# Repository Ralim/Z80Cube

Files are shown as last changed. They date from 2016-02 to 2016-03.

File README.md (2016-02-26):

# Z80Cube - Project Zeta
A 5 layer 5cm * 5cm cubish shaped z80 machine
Basically designed as a learning experience.
Big difference from other builds I have seen is the entire system runs on a 64K memory space of ram, and the atmega2560 pre-load's the bootloader into the chip on system startup.
This bootloader for the z80 then allows the user to test memory and load + execute programs.

## Layers
* Bus Display ->Led indicators for the bus
* Z80 CPU
* 64K SRAM/ROM
* Power and Programmer (Atmega 2560+flash storage to store the software)

##ToDo:
Basically everything
* Build PCBs
* Test PCBs
* Write the code for the bootloader (Going to use Arduino to keep it easy for others)
* Write arduino code for storing program packages
* Write arduino code for monitoring the bus
* write arduino code for single stepping operation

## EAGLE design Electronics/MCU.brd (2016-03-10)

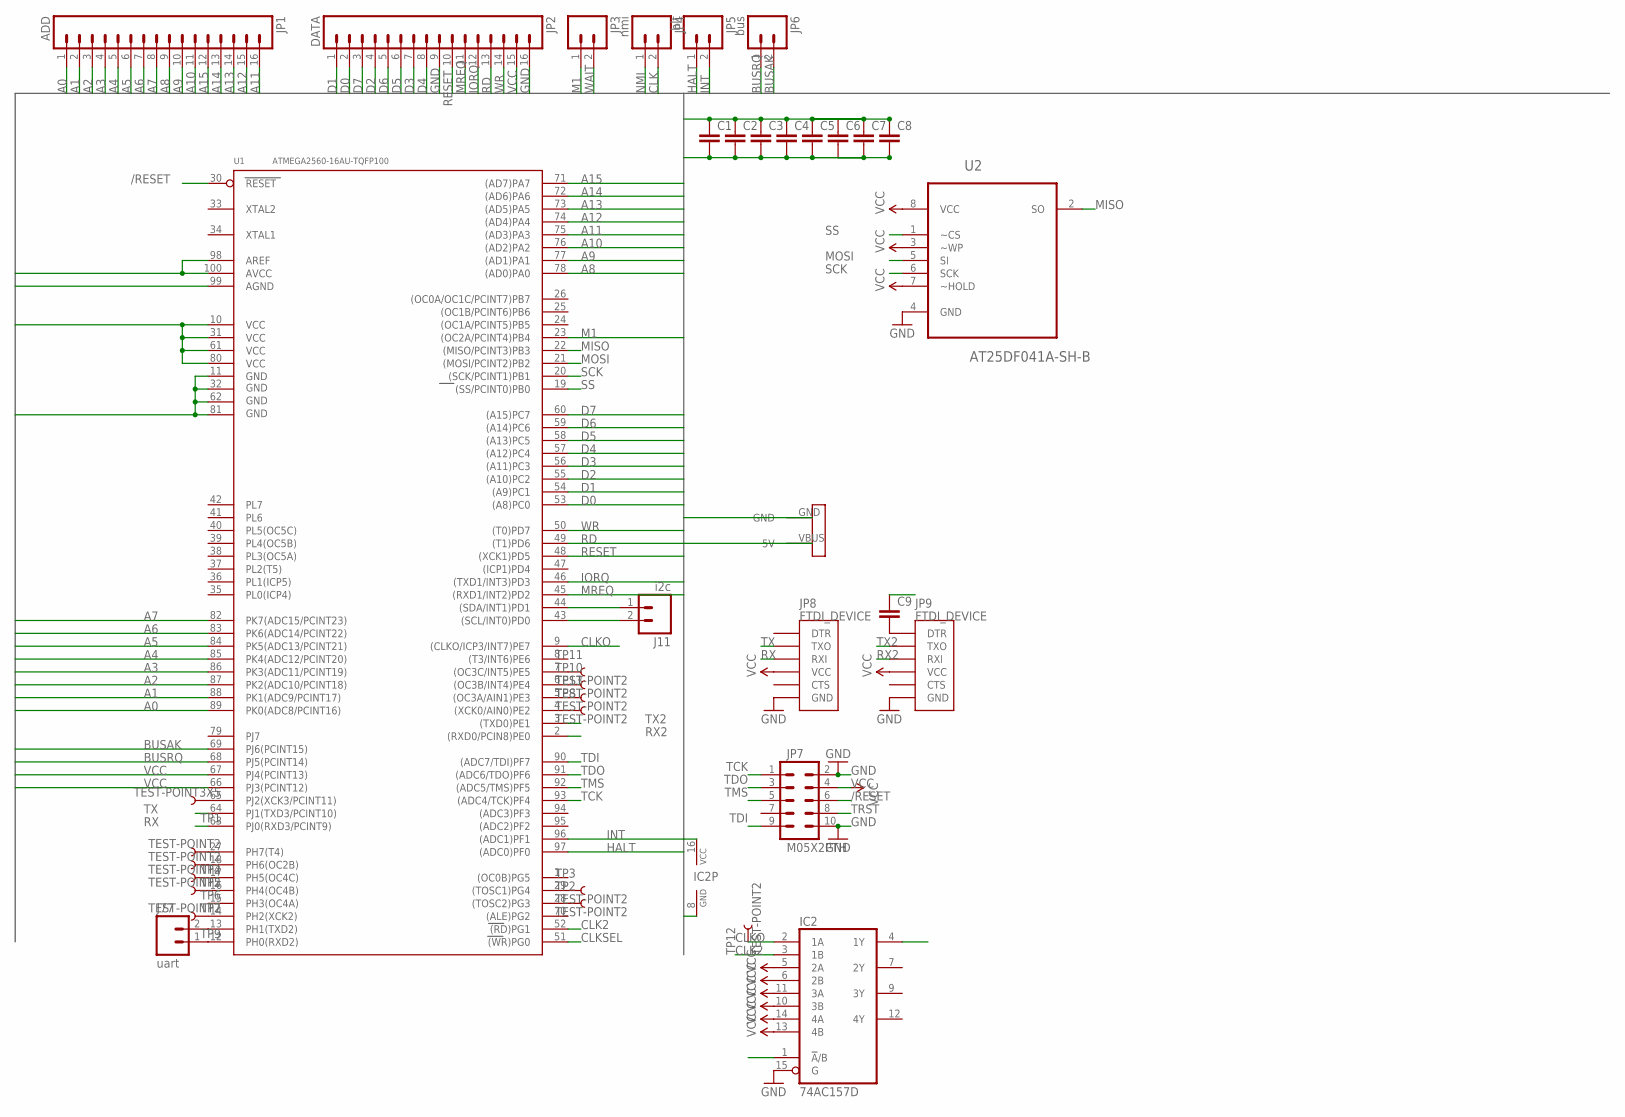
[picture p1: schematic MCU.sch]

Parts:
C1, C2, C3, C4, C5, C6, C7, C8, C9: C-EUC0805; C0805
IC2: 74AC157D; SO16
J11: i2c; 1X02
J77: uart; 1X02
JP1: ADD; 1X16
JP2: DATA; 1X16
JP3: M02PTH; 1X02
JP4: nmi; 1X02
JP5: hlt; 1X02
JP6: bus; 1X02
JP7: M05X2PTH; AVR_ICSP
JP8, JP9: FTDI_DEVICE; FTDI_DEVICE_SIDE
TP1: TEST-POINT3X5; PAD.03X.05
TP2, TP3, TP4, TP5, TP6, TP7, TP8, TP9, TP10, TP11, TP12, TP13: TEST-POINT2; PAD.02X.02
U1: ATMEGA2560-16AU-TQFP100; TQFP100-0.5-14X14MM
U2: AT25DF041A-SH-B; SOIC127P798X216-8N
U$1: USB-MICRO-PWR; USB-MICROB-PWR

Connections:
/RESET: C9.1, JP7.6, U1.30 (RESET)
A0: JP1.1, U1.89 (PK0(ADC8/PCINT16))
A1: JP1.2, U1.88 (PK1(ADC9/PCINT17))
A2: JP1.3, U1.87 (PK2(ADC10/PCINT18))
A3: JP1.4, U1.86 (PK3(ADC11/PCINT19))
A4: JP1.5, U1.85 (PK4(ADC12/PCINT20))
A5: JP1.6, U1.84 (PK5(ADC13/PCINT21))
A6: JP1.7, U1.83 (PK6(ADC14/PCINT22))
A7: JP1.8, U1.82 (PK7(ADC15/PCINT23))
A8: JP1.9, U1.78 ((AD0)PA0)
A9: JP1.10, U1.77 ((AD1)PA1)
A10: JP1.11, U1.76 ((AD2)PA2)
A11: JP1.16, U1.75 ((AD3)PA3)
A12: JP1.15, U1.74 ((AD4)PA4)
A13: JP1.14, U1.73 ((AD5)PA5)
A14: JP1.13, U1.72 ((AD6)PA6)
A15: JP1.12, U1.71 ((AD7)PA7)
BUSAK: JP6.2, U1.69 (PJ6(PCINT15))
BUSRQ: JP6.1, U1.68 (PJ5(PCINT14))
CLK: IC2.4 (1Y), JP4.2
CLK2: IC2.3 (1B), U1.52 ((RD)PG1)
CLKO: IC2.2 (1A), TP12.P$1, U1.9 ((CLKO/ICP3/INT7)PE7)
CLKSEL: IC2.1 (!A!/B), U1.51 ((WR)PG0)
D0: JP2.2, U1.53 ((A8)PC0)
D1: JP2.1, U1.54 ((A9)PC1)
D2: JP2.4, U1.55 ((A10)PC2)
D3: JP2.7, U1.56 ((A11)PC3)
D4: JP2.8, U1.57 ((A12)PC4)
D5: JP2.6, U1.58 ((A13)PC5)
D6: JP2.5, U1.59 ((A14)PC6)
D7: JP2.3, U1.60 ((A15)PC7)
GND: C1.2, C2.2, C3.2, C4.2, C5.2, C6.2, C7.2, C8.2, IC2.8 (GND), IC2.15 (G), JP2.9, JP2.16, JP7.2, JP7.10, JP8.P$6 (GND), JP9.P$6 (GND), U1.11 (GND), U1.32 (GND1), U1.62 (GND2), U1.81 (GND3), U1.99 (AGND), U2.4 (GND), U$1.GND
HALT: JP5.1, U1.97 ((ADC0)PF0)
INT: JP5.2, U1.96 ((ADC1)PF1)
IORQ: JP2.12, U1.46 ((TXD1/INT3)PD3)
M1: JP3.1, U1.23 ((OC2A/PCINT4)PB4)
MISO: U1.22 ((MISO/PCINT3)PB3), U2.2 (SO)
MOSI: U1.21 ((MOSI/PCINT2)PB2), U2.5 (SI)
MREQ: JP2.11, U1.45 ((RXD1/INT2)PD2)
unnamed: J77.1, U1.12 (PH0(RXD2))
unnamed: J77.2, U1.13 (PH1(TXD2))
unnamed: J11.1, U1.44 ((SDA/INT1)PD1)
unnamed: J11.2, U1.43 ((SCL/INT0)PD0)
unnamed: TP1.P$1, U1.65 (PJ2(XCK3/PCINT11))
unnamed: TP2.P$1, U1.28 ((TOSC2)PG3)
unnamed: TP3.P$1, U1.29 ((TOSC1)PG4)
unnamed: TP4.P$1, U1.27 (PH7(T4))
unnamed: TP5.P$1, U1.18 (PH6(OC2B))
unnamed: TP6.P$1, U1.17 (PH5(OC4C))
unnamed: TP7.P$1, U1.16 (PH4(OC4B))
unnamed: TP8.P$1, U1.4 ((XCK0/AIN0)PE2)
unnamed: TP9.P$1, U1.14 (PH2(XCK2))
unnamed: TP10.P$1, U1.6 ((OC3B/INT4)PE4)
unnamed: TP11.P$1, U1.7 ((OC3C/INT5)PE5)
unnamed: C9.2, JP9.P$1 (DTR)
unnamed: TP13.P$1, U1.5 ((OC3A/AIN1)PE3)
NMI: JP4.1
RD: JP2.13, U1.49 ((T1)PD6)
RESET: JP2.10, U1.48 ((XCK1)PD5)
RX: JP8.P$3 (RXI), U1.63 (PJ0(RXD3/PCINT9))
RX2: JP9.P$3 (RXI), U1.2 ((RXD0/PCIN8)PE0)
SCK: U1.20 ((SCK/PCINT1)PB1), U2.6 (SCK)
SS: U1.19 ((SS/PCINT0)PB0), U2.1 (~CS)
TCK: JP7.1, U1.93 ((ADC4/TCK)PF4)
TDI: JP7.9, U1.90 ((ADC7/TDI)PF7)
TDO: JP7.3, U1.91 ((ADC6/TDO)PF6)
TMS: JP7.5, U1.92 ((ADC5/TMS)PF5)
TRST: JP7.8
TX: JP8.P$2 (TXO), U1.64 (PJ1(TXD3/PCINT10))
TX2: JP9.P$2 (TXO), U1.3 ((TXD0)PE1)
VCC: C1.1, C2.1, C3.1, C4.1, C5.1, C6.1, C7.1, C8.1, IC2.5 (2A), IC2.6 (2B), IC2.10 (3B), IC2.11 (3A), IC2.13 (4B), IC2.14 (4A), IC2.16 (VCC), JP2.15, JP7.4, JP8.P$4 (VCC), JP9.P$4 (VCC), U1.10 (VCC), U1.31 (VCC1), U1.61 (VCC2), U1.66 (PJ3(PCINT12)), U1.67 (PJ4(PCINT13)), U1.80 (VCC3), U1.98 (AREF), U1.100 (AVCC), U2.3 (~WP), U2.7 (~HOLD), U2.8 (VCC), U$1.VBUS (5V)
WAIT: JP3.2
WR: JP2.14, U1.50 ((T0)PD7)

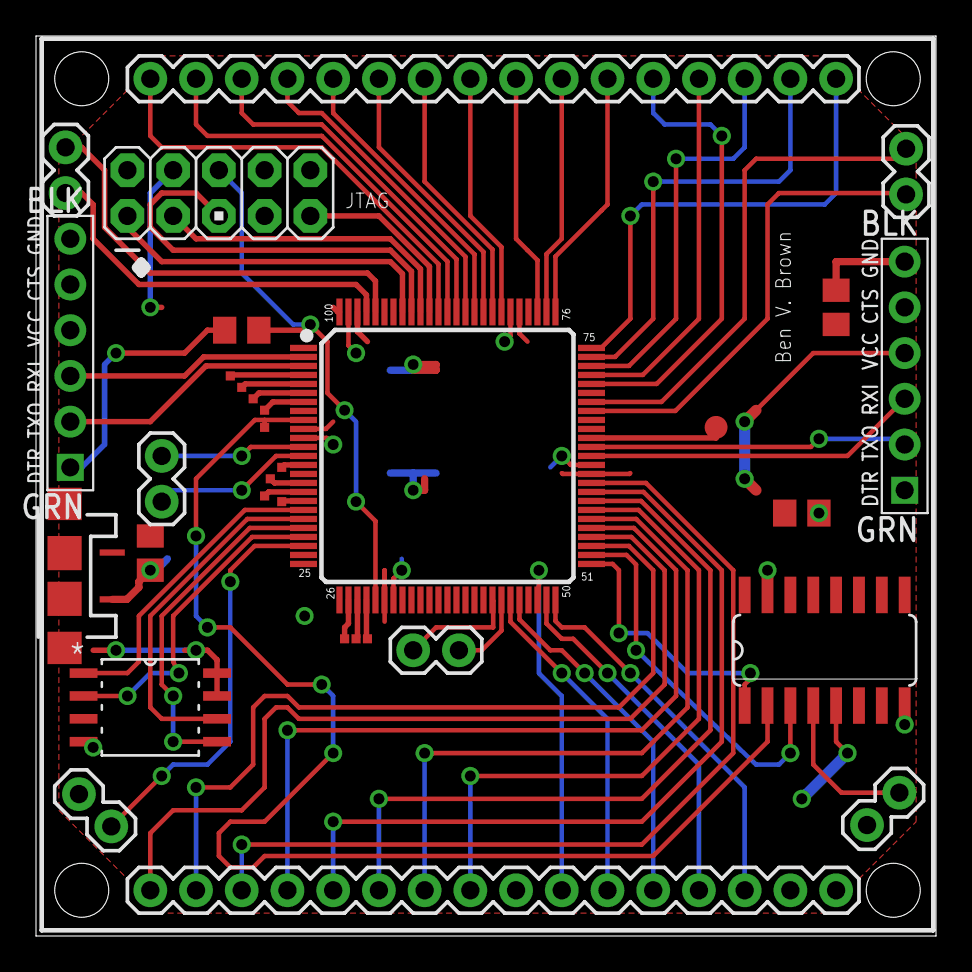
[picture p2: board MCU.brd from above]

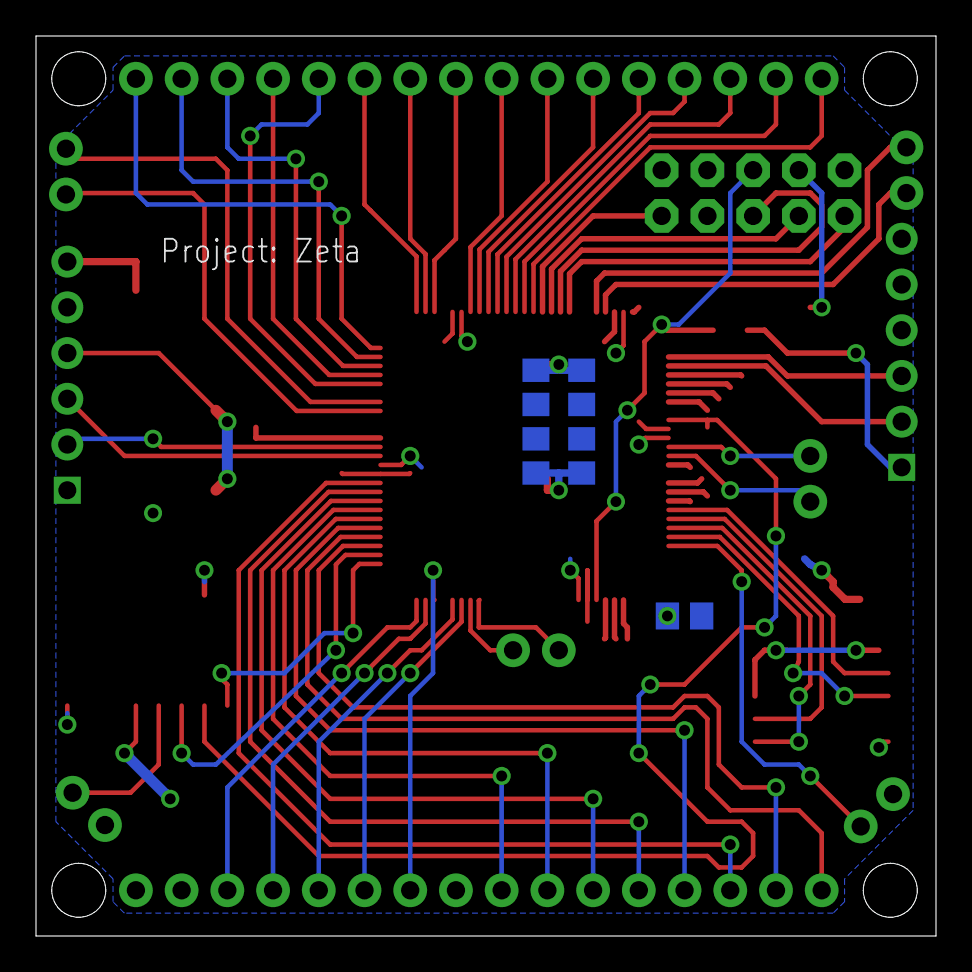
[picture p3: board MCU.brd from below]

Board: 2 copper layers, 50.0 x 50.0 mm, 37 parts (5 on the bottom side), 70 nets.

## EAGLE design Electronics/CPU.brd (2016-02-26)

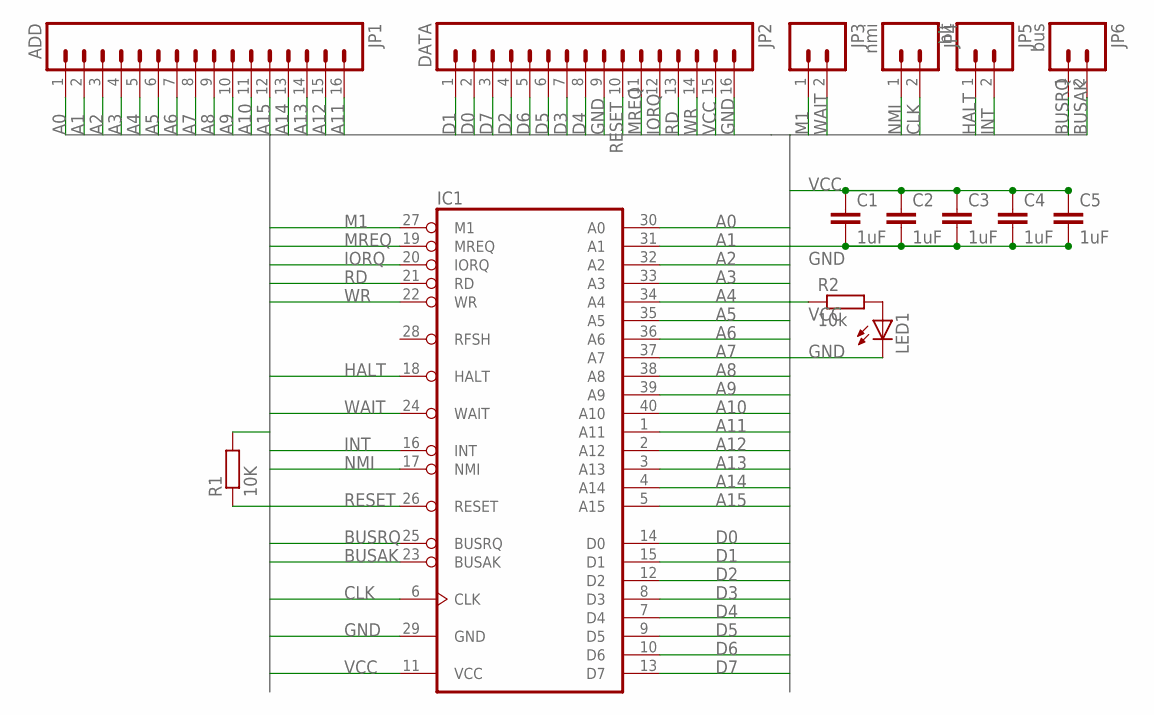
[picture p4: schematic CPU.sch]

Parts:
C1, C2, C3, C4, C5: 1uF; C0805
IC1: Z80CPU; DIL40
JP1: ADD; 1X16
JP2: DATA; 1X16
JP3: M02PTH; 1X02
JP4: nmi; 1X02
JP5: hlt; 1X02
JP6: bus; 1X02
LED1: LEDCHIP-LED0805; CHIP-LED0805
R1: 10K; M0805
R2: 10k; M0805

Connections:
A0: IC1.30 (A0), JP1.1
A1: IC1.31 (A1), JP1.2
A2: IC1.32 (A2), JP1.3
A3: IC1.33 (A3), JP1.4
A4: IC1.34 (A4), JP1.5
A5: IC1.35 (A5), JP1.6
A6: IC1.36 (A6), JP1.7
A7: IC1.37 (A7), JP1.8
A8: IC1.38 (A8), JP1.9
A9: IC1.39 (A9), JP1.10
A10: IC1.40 (A10), JP1.11
A11: IC1.1 (A11), JP1.16
A12: IC1.2 (A12), JP1.15
A13: IC1.3 (A13), JP1.14
A14: IC1.4 (A14), JP1.13
A15: IC1.5 (A15), JP1.12
BUSAK: IC1.23 (BUSAK), JP6.2
BUSRQ: IC1.25 (BUSRQ), JP6.1
CLK: IC1.6 (CLK), JP4.2
D0: IC1.14 (D0), JP2.2
D1: IC1.15 (D1), JP2.1
D2: IC1.12 (D2), JP2.4
D3: IC1.8 (D3), JP2.7
D4: IC1.7 (D4), JP2.8
D5: IC1.9 (D5), JP2.6
D6: IC1.10 (D6), JP2.5
D7: IC1.13 (D7), JP2.3
GND: C1.2, C2.2, C3.2, C4.2, C5.2, IC1.29 (GND), JP2.9, JP2.16, LED1.C
HALT: IC1.18 (HALT), JP5.1
INT: IC1.16 (INT), JP5.2
IORQ: IC1.20 (IORQ), JP2.12
M1: IC1.27 (M1), JP3.1
MREQ: IC1.19 (MREQ), JP2.11
unnamed: LED1.A, R2.2
NMI: IC1.17 (NMI), JP4.1
RD: IC1.21 (RD), JP2.13
RESET: IC1.26 (RESET), JP2.10, R1.1
VCC: C1.1, C2.1, C3.1, C4.1, C5.1, IC1.11 (VCC), JP2.15, R1.2, R2.1
WAIT: IC1.24 (WAIT), JP3.2
WR: IC1.22 (WR), JP2.14

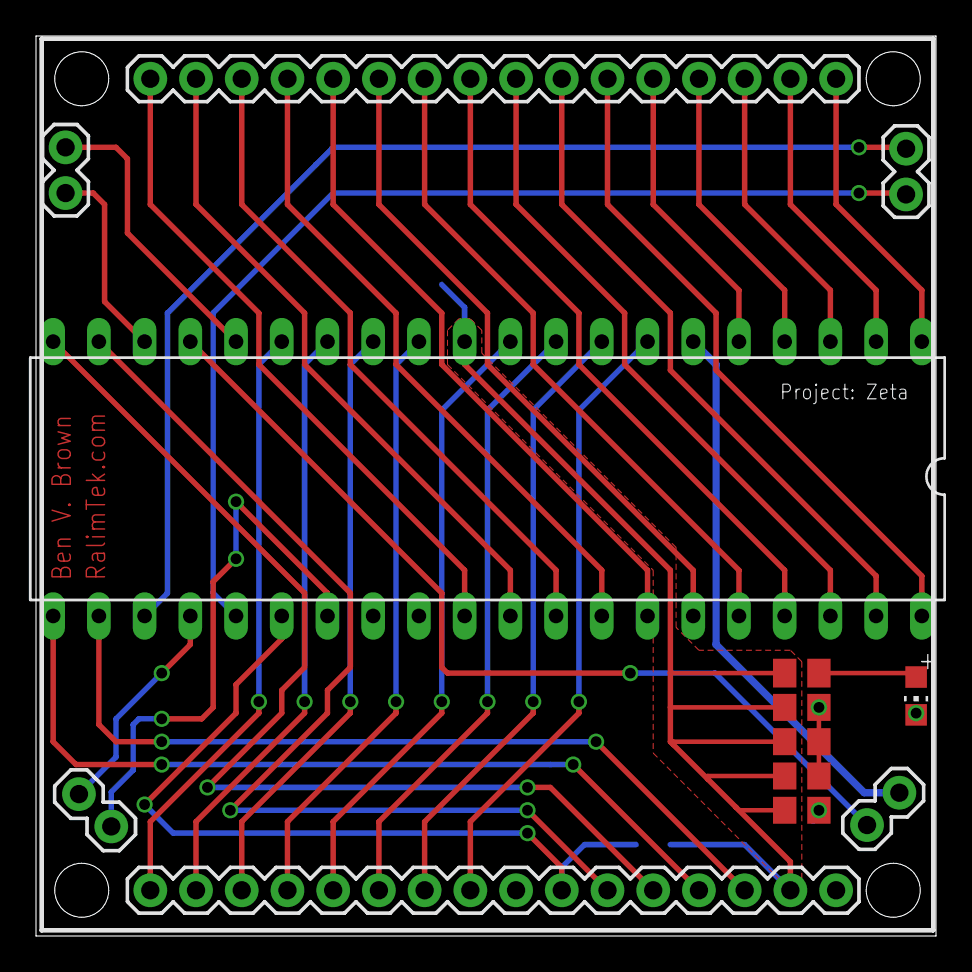
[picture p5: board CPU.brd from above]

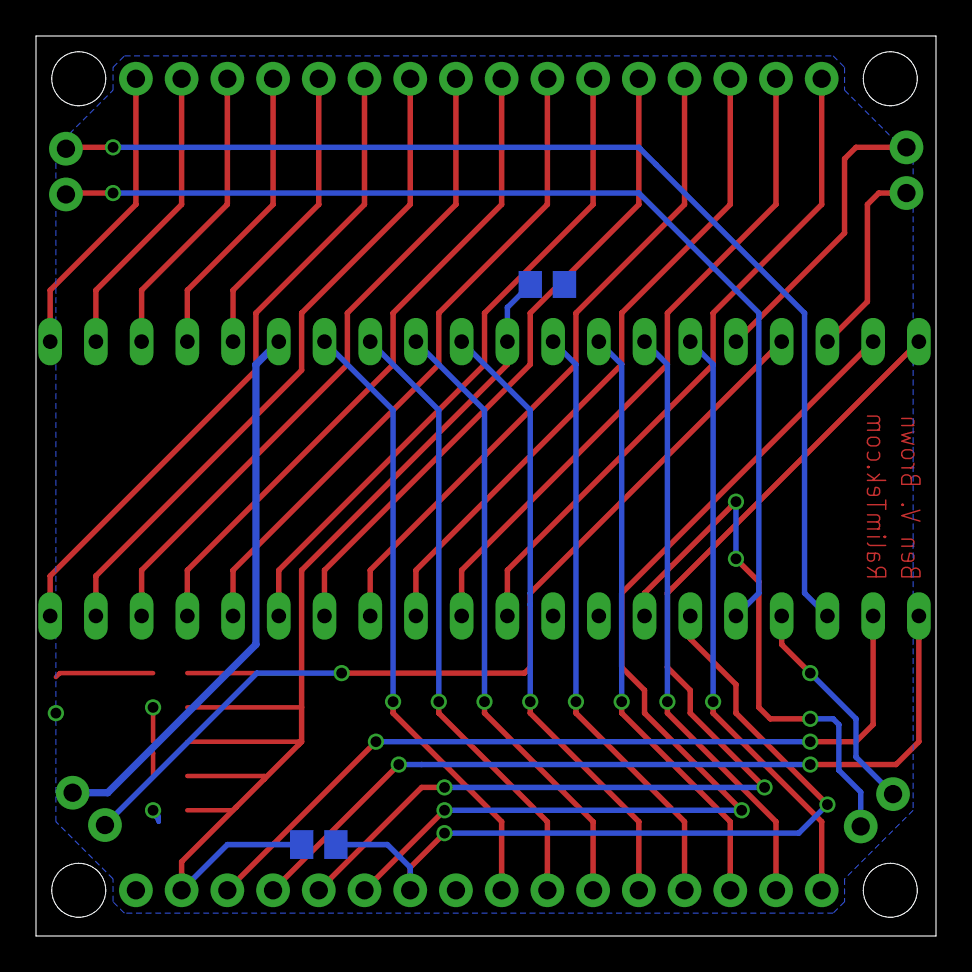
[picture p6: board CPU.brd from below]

Board: 2 copper layers, 50.0 x 50.0 mm, 15 parts (2 on the bottom side), 40 nets.

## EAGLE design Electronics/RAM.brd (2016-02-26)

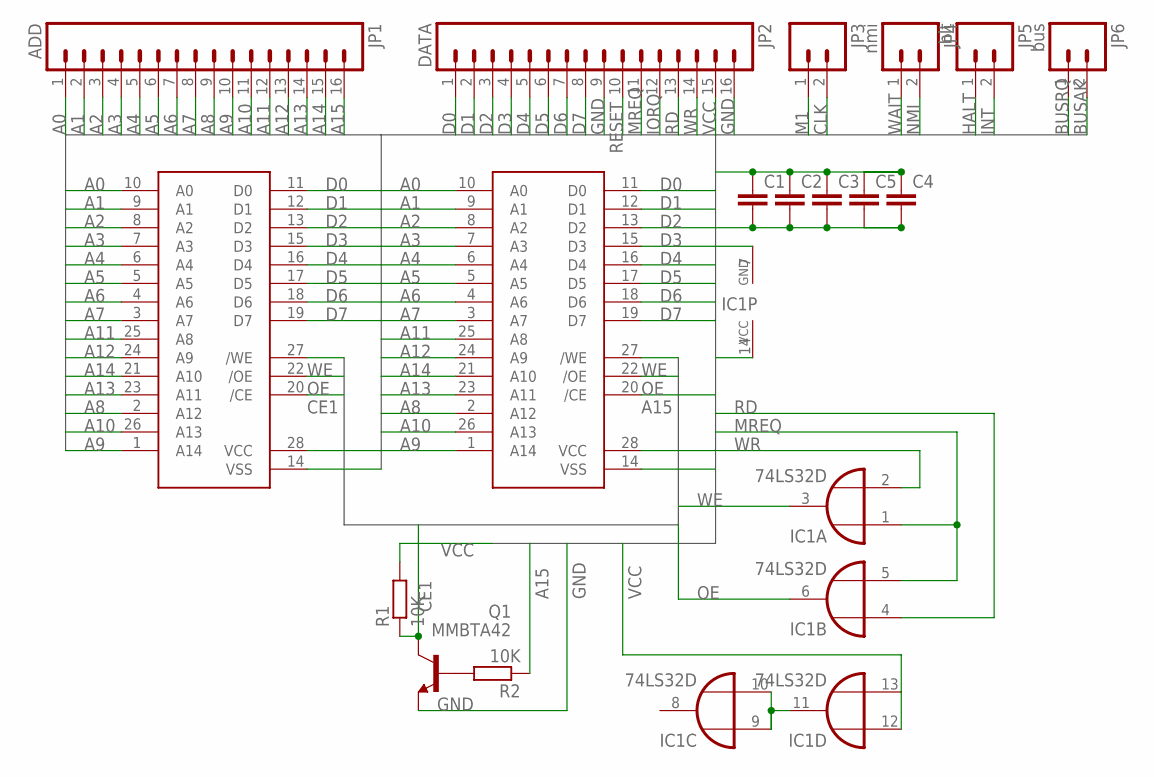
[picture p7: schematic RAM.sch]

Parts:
C1, C2, C3, C4, C5: C-EUC0805; C0805
IC1: 74LS32D; SO14
JP1: ADD; 1X16
JP2: DATA; 1X16
JP3: M02PTH; 1X02
JP4: nmi; 1X02
JP5: hlt; 1X02
JP6: bus; 1X02
Q1: MMBTA42; SOT23
R1, R2: 10K; M0805
U$1, U$2: AS7C256; SOP28

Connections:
A0: JP1.1, U$1.10 (A0), U$2.10 (A0)
A1: JP1.2, U$1.9 (A1), U$2.9 (A1)
A2: JP1.3, U$1.8 (A2), U$2.8 (A2)
A3: JP1.4, U$1.7 (A3), U$2.7 (A3)
A4: JP1.5, U$1.6 (A4), U$2.6 (A4)
A5: JP1.6, U$1.5 (A5), U$2.5 (A5)
A6: JP1.7, U$1.4 (A6), U$2.4 (A6)
A7: JP1.8, U$1.3 (A7), U$2.3 (A7)
A8: JP1.9, U$1.2 (A12), U$2.2 (A12)
A9: JP1.10, U$1.1 (A14), U$2.1 (A14)
A10: JP1.11, U$1.26 (A13), U$2.26 (A13)
A11: JP1.12, U$1.25 (A8), U$2.25 (A8)
A12: JP1.13, U$1.24 (A9), U$2.24 (A9)
A13: JP1.14, U$1.23 (A11), U$2.23 (A11)
A14: JP1.15, U$1.21 (A10), U$2.21 (A10)
A15: JP1.16, R2.1, U$2.20 (/CE)
BUSAK: JP6.2
BUSRQ: JP6.1
CE1: Q1.3 (C), R1.1, U$1.20 (/CE)
CLK: JP3.2
D0: JP2.1, U$1.11 (D0), U$2.11 (D0)
D1: JP2.2, U$1.12 (D1), U$2.12 (D1)
D2: JP2.3, U$1.13 (D2), U$2.13 (D2)
D3: JP2.4, U$1.15 (D3), U$2.15 (D3)
D4: JP2.5, U$1.16 (D4), U$2.16 (D4)
D5: JP2.6, U$1.17 (D5), U$2.17 (D5)
D6: JP2.7, U$1.18 (D6), U$2.18 (D6)
D7: JP2.8, U$1.19 (D7), U$2.19 (D7)
GND: C1.2, C2.2, C3.2, C4.2, C5.2, IC1.7 (GND), JP2.9, JP2.16, Q1.2 (E), U$1.14 (VSS), U$2.14 (VSS)
HALT: JP5.1
INT: JP5.2
IORQ: JP2.12
M1: JP3.1
MREQ: IC1.1 (I0), IC1.5 (I1), JP2.11
unnamed: IC1.9 (I0), IC1.10 (I1), IC1.11 (O)
unnamed: Q1.1 (B), R2.2
NMI: JP4.2
OE: IC1.6 (O), U$1.22 (/OE), U$2.22 (/OE)
RD: IC1.4 (I0), JP2.13
RESET: JP2.10
VCC: C1.1, C2.1, C3.1, C4.1, C5.1, IC1.12 (I0), IC1.13 (I1), IC1.14 (VCC), JP2.15, R1.2, U$1.28 (VCC), U$2.28 (VCC)
WAIT: JP4.1
WE: IC1.3 (O), U$1.27 (/WE), U$2.27 (/WE)
WR: IC1.2 (I1), JP2.14

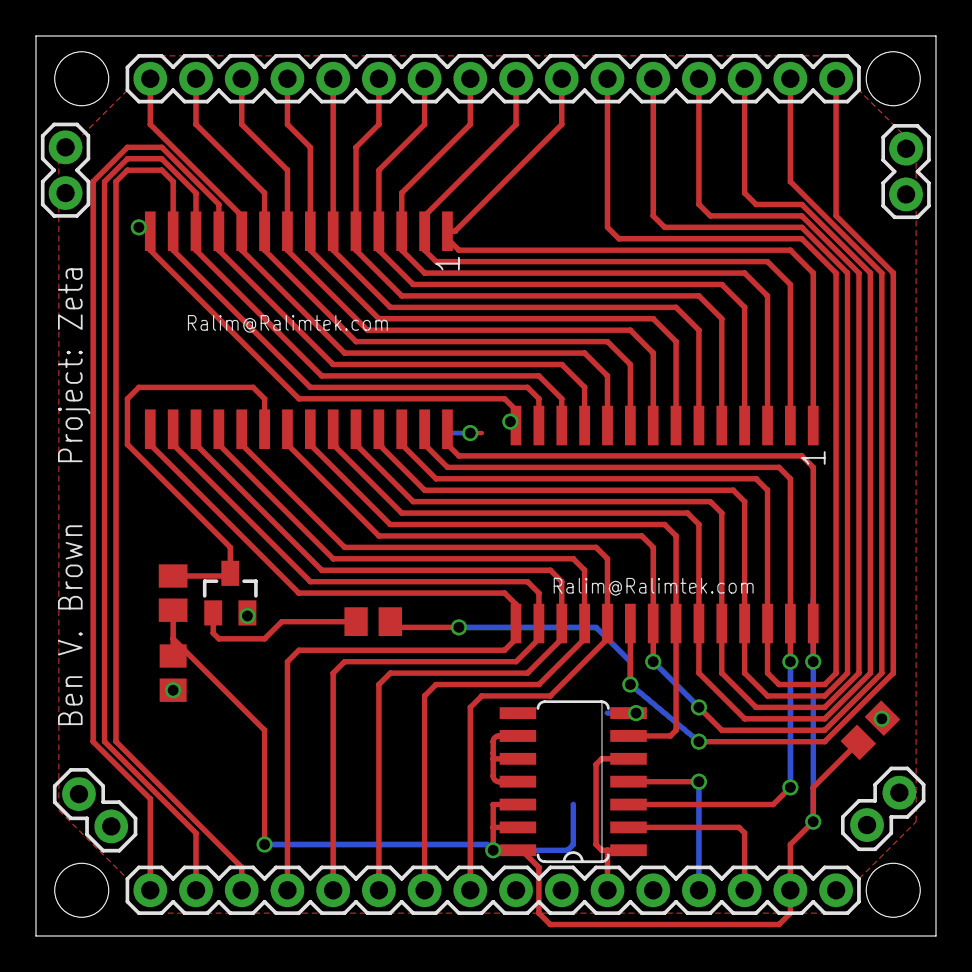
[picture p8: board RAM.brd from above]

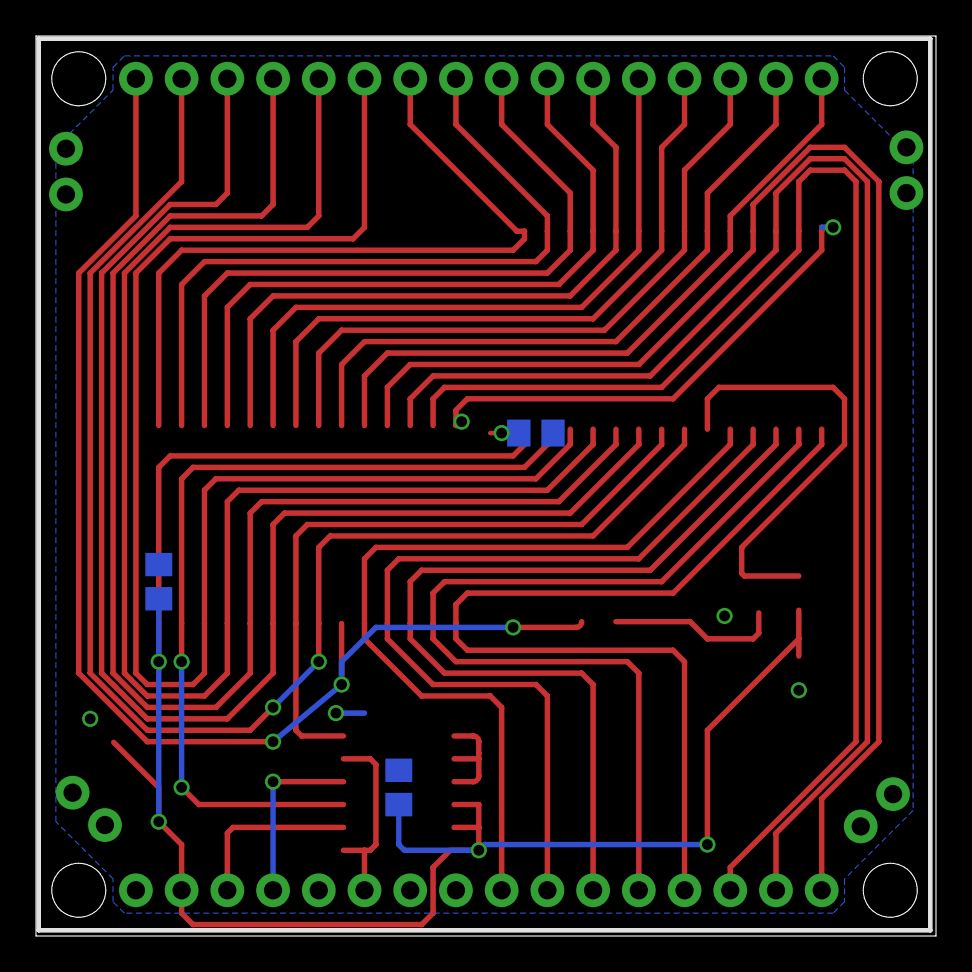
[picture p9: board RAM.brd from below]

Board: 2 copper layers, 50.0 x 50.0 mm, 17 parts (3 on the bottom side), 34 nets.

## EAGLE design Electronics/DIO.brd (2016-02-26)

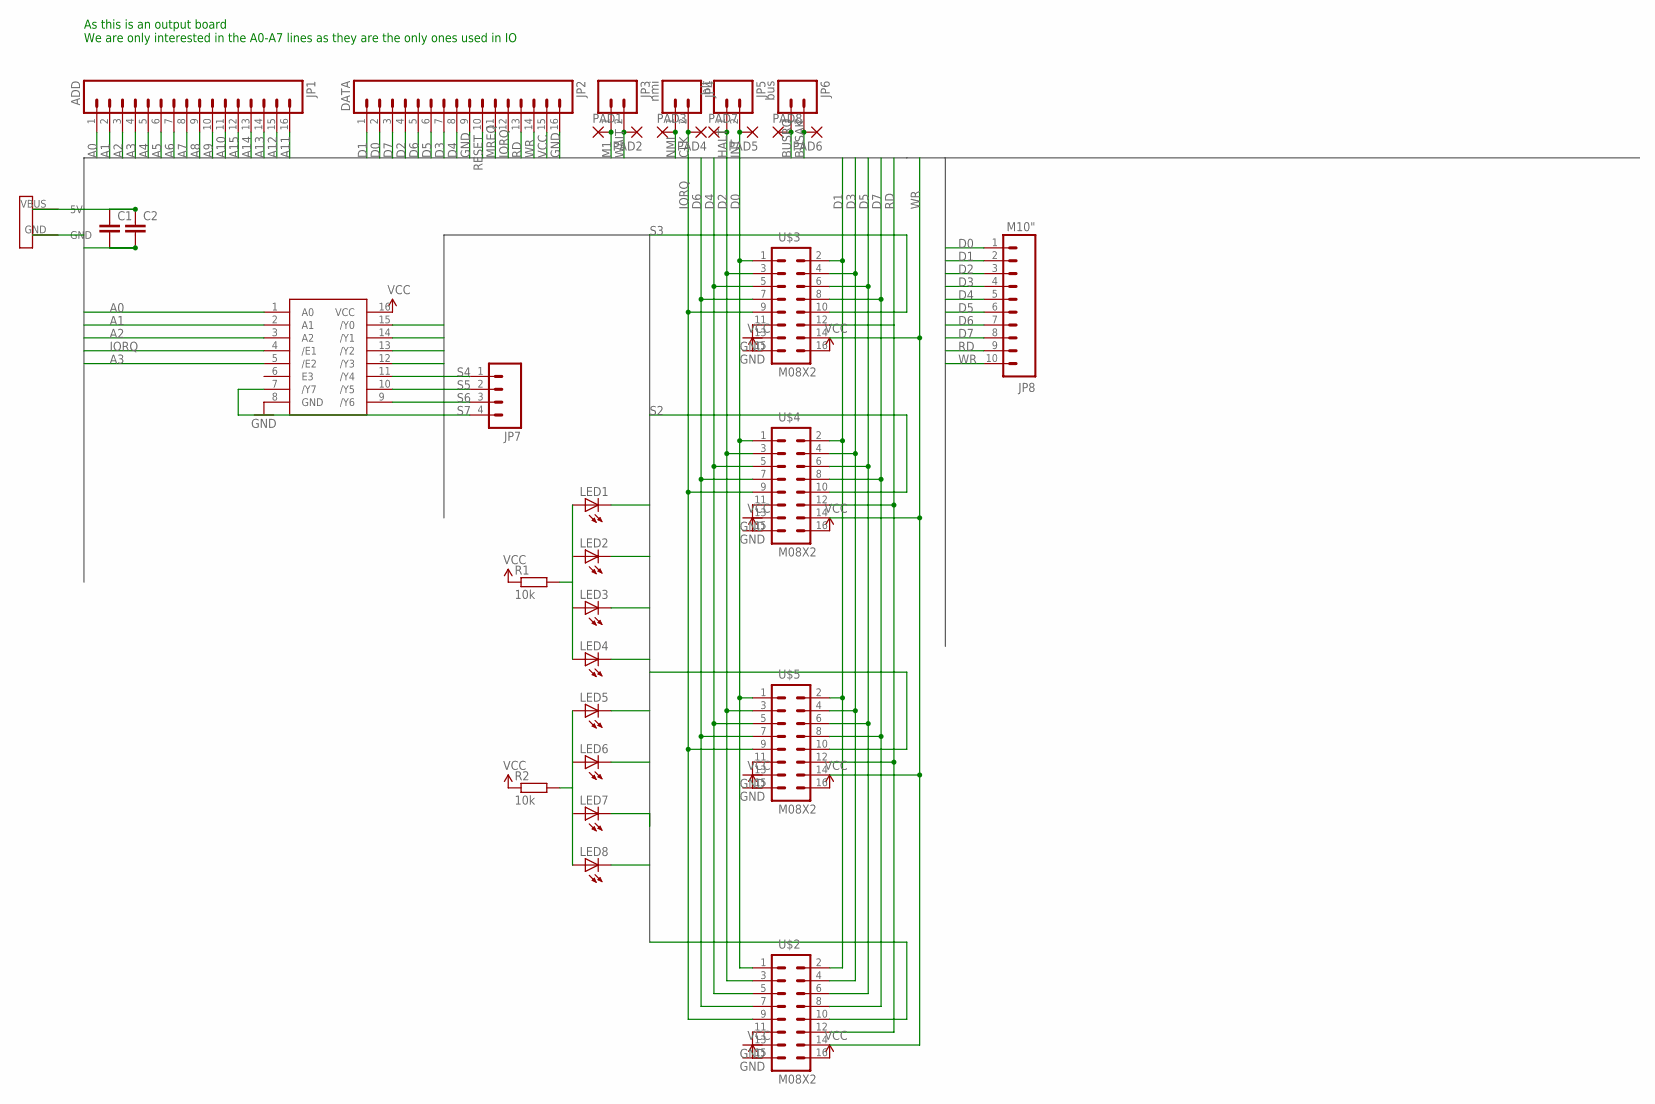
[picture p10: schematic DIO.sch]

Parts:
C1, C2: C-EUC0805; C0805
JP1: ADD; 1X16
JP2: DATA; 1X16
JP3: M02PTH; 1X02
JP4: nmi; 1X02
JP5: hlt; 1X02
JP6: bus; 1X02
JP7: M04PTH; 1X04
JP8: M10"; 1X10
LED1, LED2, LED3, LED4, LED5, LED6, LED7, LED8: LEDCHIP-LED0805; CHIP-LED0805
PAD1, PAD2, PAD3, PAD4, PAD5, PAD6, PAD7, PAD8: SMD2; SMD1,27-2,54
R1, R2: 10k; M0805
U$1: 74LVC138AD; SO016
U$2, U$3, U$4, U$5: M08X2; 2X8
U$6: USB-MICRO-PWR; USB-MICROB-PWR

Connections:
A0: JP1.1, U$1.1 (A0)
A1: JP1.2, U$1.2 (A1)
A2: JP1.3, U$1.3 (A2)
A3: JP1.4, U$1.5 (/E2)
A4: JP1.5
A5: JP1.6
A6: JP1.7
A7: JP1.8
A8: JP1.9
A9: JP1.10
A10: JP1.11
A11: JP1.16
A12: JP1.15
A13: JP1.14
A14: JP1.13
A15: JP1.12
BUSAK: JP6.2, PAD6.1
BUSRQ: JP6.1, PAD8.1
CLK: JP4.2, PAD4.1
D0: JP2.2, JP8.1, U$2.1, U$3.1, U$4.1, U$5.1
D1: JP2.1, JP8.2, U$2.2, U$3.2, U$4.2, U$5.2
D2: JP2.4, JP8.3, U$2.3, U$3.3, U$4.3, U$5.3
D3: JP2.7, JP8.4, U$2.4, U$3.4, U$4.4, U$5.4
D4: JP2.8, JP8.5, U$2.5, U$3.5, U$4.5, U$5.5
D5: JP2.6, JP8.6, U$2.6, U$3.6, U$4.6, U$5.6
D6: JP2.5, JP8.7, U$2.7, U$3.7, U$4.7, U$5.7
D7: JP2.3, JP8.8, U$2.8, U$3.8, U$4.8, U$5.8
GND: C1.2, C2.2, JP2.9, JP2.16, U$1.8 (GND), U$2.11, U$2.13, U$3.11, U$3.13, U$4.11, U$4.13, U$5.11, U$5.13, U$6.GND
HALT: JP5.1, PAD7.1
INT: JP5.2, PAD5.1
IORQ: JP2.12, U$1.4 (/E1), U$2.9, U$3.9, U$4.9, U$5.9
M1: JP3.1, PAD1.1
MREQ: JP2.11
unnamed: LED1.A, LED2.A, LED3.A, LED4.A, R1.2
unnamed: LED5.A, LED6.A, LED7.A, LED8.A, R2.2
NMI: JP4.1, PAD3.1
RD: JP2.13, JP8.9, U$2.12, U$3.12, U$4.12, U$5.12
RESET: JP2.10
S0: LED1.C, U$1.15 (/Y0), U$2.10
S1: LED2.C, U$1.14 (/Y1), U$5.10
S2: LED3.C, U$1.13 (/Y2), U$4.10
S3: LED4.C, U$1.12 (/Y3), U$3.10
S4: JP7.1, LED5.C, U$1.11 (/Y4)
S5: JP7.2, LED6.C, U$1.10 (/Y5)
S6: JP7.3, LED7.C, U$1.9 (/Y6)
S7: JP7.4, LED8.C, U$1.7 (/Y7)
VCC: C1.1, C2.1, JP2.15, R1.1, R2.1, U$1.16 (VCC), U$2.15, U$2.16, U$3.15, U$3.16, U$4.15, U$4.16, U$5.15, U$5.16, U$6.VBUS (5V)
WAIT: JP3.2, PAD2.1
WR: JP2.14, JP8.10, U$2.14, U$3.14, U$4.14, U$5.14

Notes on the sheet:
As this is an output board We are only interested in the A0-A7 lines as they are the only ones used in IO

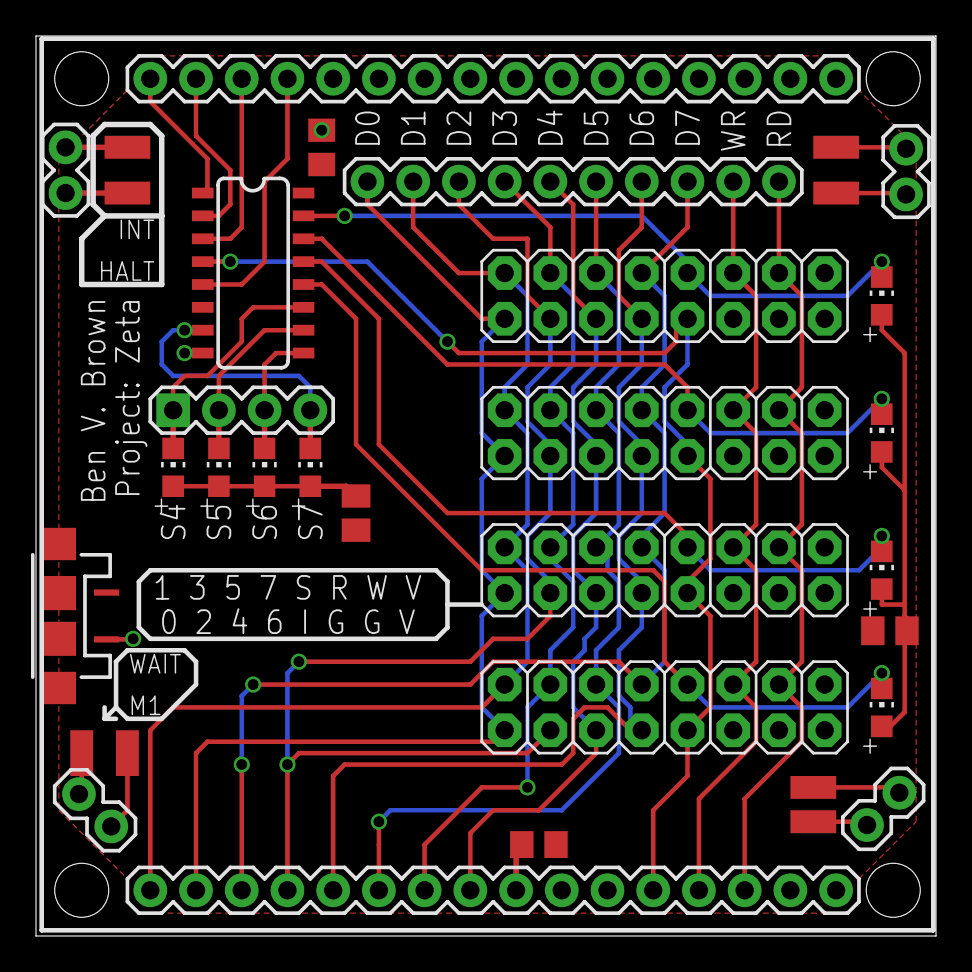
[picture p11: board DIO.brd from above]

Board: 2 copper layers, 50.0 x 50.0 mm, 34 parts (0 on the bottom side), 35 nets.

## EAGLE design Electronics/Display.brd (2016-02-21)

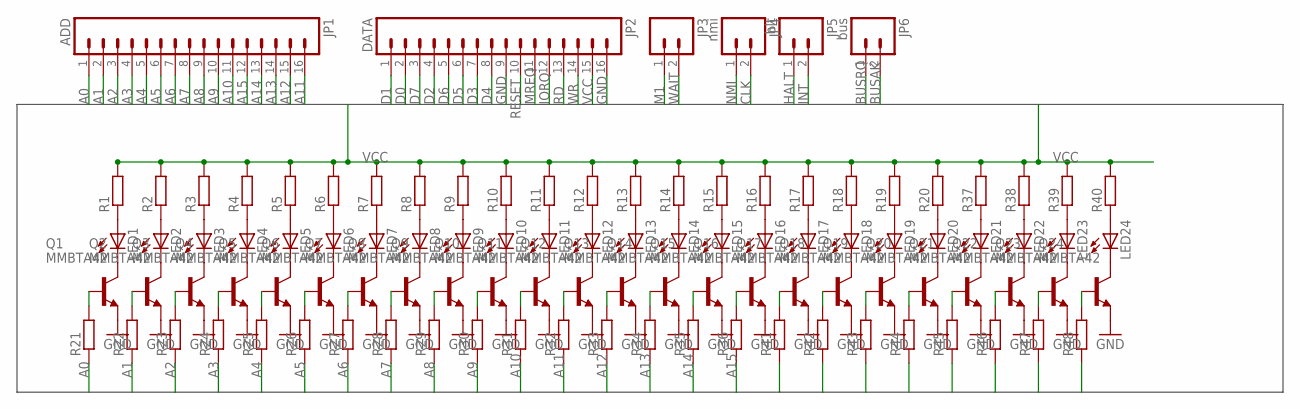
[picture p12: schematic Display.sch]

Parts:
JP1: ADD; 1X16
JP2: DATA; 1X16
JP3: M02PTH; 1X02
JP4: nmi; 1X02
JP5: hlt; 1X02
JP6: bus; 1X02
LED1, LED2, LED3, LED4, LED5, LED6, LED7, LED8, LED9, LED10, LED11, LED12, LED13, LED14, LED15, LED16, LED17, LED18, LED19, LED20, LED21, LED22, LED23, LED24: LEDCHIP-LED0805; CHIP-LED0805
Q1, Q2, Q3, Q4, Q5, Q6, Q7, Q8, Q9, Q10, Q11, Q12, Q13, Q14, Q15, Q16, Q17, Q18, Q19, Q20, Q21, Q22, Q23, Q24: MMBTA42; SOT23
R1, R2, R3, R4, R5, R6, R7, R8, R9, R10, R11, R12, R13, R14, R15, R16, R17, R18, R19, R20, R21, R22, R23, R24, R25, R26, R27, R28, R29, R30, R31, R32, R33, R34, R35, R36, R37, R38, R39, R40, R41, R42, R43, R44, R45, R46, R47, R48: R-EU_M0805; M0805

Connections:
A0: JP1.1, R21.1
A1: JP1.2, R22.1
A2: JP1.3, R23.1
A3: JP1.4, R24.1
A4: JP1.5, R25.1
A5: JP1.6, R26.1
A6: JP1.7, R27.1
A7: JP1.8, R28.1
A8: JP1.9, R29.1
A9: JP1.10, R30.1
A10: JP1.11, R31.1
A11: JP1.16, R32.1
A12: JP1.15, R33.1
A13: JP1.14, R34.1
A14: JP1.13, R35.1
A15: JP1.12, R36.1
BUSAK: JP6.2
BUSRQ: JP6.1
CLK: JP4.2
D0: JP2.2, R41.1
D1: JP2.1, R42.1
D2: JP2.4, R43.1
D3: JP2.7, R44.1
D4: JP2.8, R45.1
D5: JP2.6, R46.1
D6: JP2.5, R47.1
D7: JP2.3, R48.1
GND: JP2.9, JP2.16, Q1.2 (E), Q2.2 (E), Q3.2 (E), Q4.2 (E), Q5.2 (E), Q6.2 (E), Q7.2 (E), Q8.2 (E), Q9.2 (E), Q10.2 (E), Q11.2 (E), Q12.2 (E), Q13.2 (E), Q14.2 (E), Q15.2 (E), Q16.2 (E), Q17.2 (E), Q18.2 (E), Q19.2 (E), Q20.2 (E), Q21.2 (E), Q22.2 (E), Q23.2 (E), Q24.2 (E)
HALT: JP5.1
INT: JP5.2
IORQ: JP2.12
M1: JP3.1
MREQ: JP2.11
unnamed: LED1.A, R1.1
unnamed: LED1.C, Q1.3 (C)
unnamed: LED2.A, R2.1
unnamed: LED2.C, Q2.3 (C)
unnamed: LED3.A, R3.1
unnamed: LED3.C, Q3.3 (C)
unnamed: LED4.A, R4.1
unnamed: LED4.C, Q4.3 (C)
unnamed: LED5.A, R5.1
unnamed: LED5.C, Q5.3 (C)
unnamed: LED6.A, R6.1
unnamed: LED6.C, Q6.3 (C)
unnamed: LED7.A, R7.1
unnamed: LED7.C, Q7.3 (C)
unnamed: LED8.A, R8.1
unnamed: LED8.C, Q8.3 (C)
unnamed: LED9.A, R9.1
unnamed: LED9.C, Q9.3 (C)
unnamed: LED10.A, R10.1
unnamed: LED10.C, Q10.3 (C)
unnamed: LED11.A, R11.1
unnamed: LED11.C, Q11.3 (C)
unnamed: LED12.A, R12.1
unnamed: LED12.C, Q12.3 (C)
unnamed: LED13.A, R13.1
unnamed: LED13.C, Q13.3 (C)
unnamed: LED14.A, R14.1
unnamed: LED14.C, Q14.3 (C)
unnamed: LED15.A, R15.1
unnamed: LED15.C, Q15.3 (C)
unnamed: LED16.A, R16.1
unnamed: LED16.C, Q16.3 (C)
unnamed: Q24.1 (B), R48.2
unnamed: Q23.1 (B), R47.2
unnamed: Q22.1 (B), R46.2
unnamed: Q21.1 (B), R45.2
unnamed: Q20.1 (B), R44.2
unnamed: Q19.1 (B), R43.2
unnamed: Q18.1 (B), R42.2
unnamed: Q17.1 (B), R41.2
unnamed: LED17.A, R17.1
unnamed: LED17.C, Q17.3 (C)
unnamed: LED18.A, R18.1
unnamed: LED18.C, Q18.3 (C)
unnamed: Q16.1 (B), R36.2
unnamed: Q15.1 (B), R35.2
unnamed: Q14.1 (B), R34.2
unnamed: Q13.1 (B), R33.2
unnamed: Q12.1 (B), R32.2
unnamed: Q11.1 (B), R31.2
unnamed: Q10.1 (B), R30.2
unnamed: Q9.1 (B), R29.2
unnamed: Q8.1 (B), R28.2
unnamed: Q7.1 (B), R27.2
unnamed: Q6.1 (B), R26.2
unnamed: Q5.1 (B), R25.2
unnamed: Q4.1 (B), R24.2
unnamed: Q3.1 (B), R23.2
unnamed: Q2.1 (B), R22.2
unnamed: Q1.1 (B), R21.2
unnamed: LED19.A, R19.1
unnamed: LED19.C, Q19.3 (C)
unnamed: LED20.A, R20.1
unnamed: LED20.C, Q20.3 (C)
unnamed: LED21.A, R37.1
unnamed: LED21.C, Q21.3 (C)
unnamed: LED22.A, R38.1
unnamed: LED22.C, Q22.3 (C)
unnamed: LED23.A, R39.1
unnamed: LED23.C, Q23.3 (C)
unnamed: LED24.A, R40.1
unnamed: LED24.C, Q24.3 (C)
NMI: JP4.1
RD: JP2.13
RESET: JP2.10
VCC: JP2.15, R1.2, R2.2, R3.2, R4.2, R5.2, R6.2, R7.2, R8.2, R9.2, R10.2, R11.2, R12.2, R13.2, R14.2, R15.2, R16.2, R17.2, R18.2, R19.2, R20.2, R37.2, R38.2, R39.2, R40.2
WAIT: JP3.2
WR: JP2.14



Board: 2 copper layers, 50.0 x 50.0 mm, 102 parts (72 on the bottom side), 98 nets.

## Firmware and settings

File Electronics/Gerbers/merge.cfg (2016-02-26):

# This configuration file demonstrates panelizing multiple, different jobs.
# We panelize the HEXAPOD job and several copies of the Proj1 job.

##############################################################################
# In the [DEFAULT] section you can create global names to save typing the same
# directory name, for example, over and over.
##############################################################################
[DEFAULT]

# Change projdir to wherever your project files are, for example:
#
#   projdir = /home/stuff/projects/test
#
# or relative pathname from where you are running GerbMerge
#
#   projdir = testdata
#
# or if all files are in the current directory (as in this example):
#
#   projdir = .
projdir = .

# For convenience, this is the base name of the merged output files.
MergeOut = merge2

#############################################################################
# The [Options] section defines settings that control how the input files are
# read and how the output files are generated.
#############################################################################
[Options]

################################################################
#
#               Settings that are very important
#
################################################################

# Option indicating name of file that maps Excellon tool codes to drill sizes.
# This is not necessary if the Excellon files have embedded tool sizes, or if a
# tool list is specified as part of the job description. The ToolList option
# here is the "last resort" for mapping tool codes to tool sizes. Most recent
# PCB programs embed drill size information right in the Excellon file, so this
# option should not be necessary and can be commented out.
#ToolList=proj1.drl

# Optional indication of the number of decimal places in input Excellon drill
# files. The default is 4 which works for recent versions of Eagle (since
# version 4.11r12), as well as Orcad and PCB. Older versions of Eagle use 3
# decimal places.
#ExcellonDecimals = 4

################################################################
#
#             Settings that are somewhat important
#
################################################################

# Which layers to draw cut lines on. Omit this option or set to 'None' for no
# cut lines. Cut lines are borders around each job that serve as guides for
# cutting the panel into individual jobs. Option 'CutLineWidth' sets the
# thickness of these cut lines.
#
# NOTE: Layer names are ALL LOWERCASE, even if you define them with uppercase
# letters below.
CutLineLayers = *topsilkscreen,*bottomsilkscreen

# Which layers to draw crop marks on. Omit this option or set to 'None' for no
# crop marks. Crop marks are small L-shaped marks at the 4 corners of the final
# panel. These practically define the extents of the panel and are required by
# some board manufacturers. Crop marks are also required if you want to leave
# extra space around the final panel for tooling or handling.  Option
# 'CropMarkWidth' sets the thickness of these crop marks.
#
# NOTE: Layer names are ALL LOWERCASE, even if you define them with uppercase
# letters below.
CropMarkLayers = *topsilkscreen,*bottomsilkscreen
OutlineLayerFile=merge2.oln
#OutlineLayers = *toplayer,*bottomlayer,*topsilkscreen,*bottomsilkscreen,*topsoldermask,*bottomsoldermask

# Set this option to the name of a file in which to write a Gerber fabrication
# drawing. Some board manufacturers require a fabrication drawing with panel
# dimensions and drill hit marks and drill legend. There's no harm in creating
# this file...you can ignore it if you don't need it.
FabricationDrawingFile = %(mergeout)s.fab

# If FabricationDrawingFile is specified, you can provide an optional file name
# of a file containing arbitrary text to add to the fabrication drawing. This
# text can indicate manufacturing information, contact information, etc.
#FabricationDrawingText = %(projdir)s/fabdwg.txt

# Option to generate leading zeros in the output Excellon drill file, i.e., to
# NOT use leading-zero suppression. Some Gerber viewers cannot properly guess
# the Excellon file format when there are no leading zeros.  Set this option to
# 1 if your Gerber viewer is putting the drill holes in far off places that do
# not line up with component pads.
ExcellonLeadingZeros = 0

# Optional additional Gerber layer on which to draw a rectangle defining the
# extents of the entire panelized job. This will create a Gerber file (with
# name specified by this option) that simply contains a rectangle defining the
# outline of the final panel. This outline file is useful for circuit board
# milling to indicate a path for the router tool. There's no harm in creating
# this file...you can ignore it if you don't need it.
OutlineLayerFile = %(mergeout)s.oln
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

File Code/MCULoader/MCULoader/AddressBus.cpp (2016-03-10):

/*
* AddressBus.cpp
*
* Created: 10/03/2016 9:22:27 PM
* Author: Ralim
*/


#include "AddressBus.h"

// default constructor
AddressBus::AddressBus()
{
	
	//Data pins 0-7  = PortC
	//Addr pins 8-15 = PortA
	//Addr pins 0-7  = PortK
	DDRC=DDRA=DDRK=0;//all inputs for now
	
} //AddressBus

// default destructor
AddressBus::~AddressBus()
{
} //~AddressBus

void AddressBus::takeOverBus()
{
	DDRJ &= ~(1<<PJ5);//request by pulling the BUSRQ Low
	PORTJ &= ~(1<<PJ5);// ^
	uint8_t val =0xFF;
	while((val & PJ5) == 0x00)
	{
		val = PORTJ;//latch the port reading
	}
//we should now have free run of the bus
}
void AddressBus::readBus(uint8_t* data,uint16_t* address)
{
	(*data) = PORTC;
	(*address) = ((uint16_t)PORTA)<<8 | PORTK;
	
}
//Writes the data to the data bus lines and also set the memory/io line
void AddressBus::writeBus(uint8_t data, uint16_t address,bool memory=true)
{
	
	DDRA=0xFF;//addH
	DDRC=0xFF;//Data
	DDRK=0xFF;//addL
	PORTK=(uint8_t)address;
	PORTA=address>>8;
	PORTC=data;//save the data output
	if(memory)
	{
		//write the MEMRQ line low
		DDRD &=~(1<<PD2);//make it an output
		PORTD &=~(1<<PD2);//write it low
		
	}
	else
	{
		//write the IOREQ line low
		DDRD &=~(1<<PD3);//make it an output
		PORTD &=~(1<<PD3);//write it low
	}
}

//This will pulse the write line low long enough to latch the value into the memory at the other end.
void AddressBus::writeValue()
{
	DDRD &=~(1<<PD7);//make it an output
	PORTD &=~(1<<PD7);//write it low
	for(uint16_t i=0;i<65000;i++){}//delay a bit
	PORTD |=(1<<PD7);//write it high
	DDRD |= (1<<PD7);//make the pin an input
}
//this pulls the read line low and then reads the data on the bus, followed by releasing the read line
void AddressBus::readValue(uint8_t* data, uint16_t* address)
{
	DDRD &=~(1<<PD6);//make it an output
	PORTD &=~(1<<PD6);//write it low
	for(uint16_t i=0;i<65000;i++){}//delay a bit
	readBus(data,address);//read in the values that are on the data lines
	PORTD |=(1<<PD6);//write it high
	DDRD |= (1<<PD6);//make the pin an input
	
}

void AddressBus::singleStep()
{
	
	
}

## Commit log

2016-02-21 Adding RAM
    Add the 64K RAM/ROM
    [RAM.brd, RAM.sch]
2016-02-21 Add CPU
    Add the CPU board
    [CPU.brd, CPU.sch]
2016-02-21 Add MCU board
    add atmega 2560 as bootloader
    [MCU.brd, MCU.sch]
2016-02-21 Add display
    Adding display status board (leds show signal levels on all the header
    pins).
    [Display.brd, Display.sch]
2016-02-22 Add uart0 breakout
    [MCU.brd, MCU.sch]
2016-02-22 Layout changes
    [CPU.brd, MCU.brd, MCU.sch]
2016-02-22 Fix up caps on ram/mcu board
    [MCU.brd, MCU.sch, RAM.brd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]
2016-02-22 Update board outlines
    Adding white line around boards for de-panelization
    [CPU.brd, CPU.sch, MCU.brd]
2016-02-22 Create DIO board + fix MCU picture
    [DIO.brd, DIO.sch]
2016-02-26 Route DIO Breakout + update Text
    [CPU.brd, DIO.brd, DIO.sch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]
2016-03-10 Create Atmel Studio Project
    [MCU.sch]
2016-03-10 Expanding bus driver
    Added basic features to control the bus lines
    [MCU.brd, MCU.sch]

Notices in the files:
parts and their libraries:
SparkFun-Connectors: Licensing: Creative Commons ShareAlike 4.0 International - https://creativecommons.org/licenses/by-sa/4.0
